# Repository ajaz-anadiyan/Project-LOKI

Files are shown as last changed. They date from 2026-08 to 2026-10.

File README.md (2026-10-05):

# 🚀 Project Loki: Bidirectional Free-Space Optical Communication

**Project Loki** is a two-way laser communication system built for the NIMS Dubai Expo. It demonstrates NASA's latest Free-Space Optical (FSO) satellite technology by transmitting data wirelessly through beams of light instead of radio waves. 

The project features **two identical transceiver stations**. Both stations can send and receive audio data at the exact same time over a single optical link.

---

## 🌟 Key Features
* **Two-Way Link:** Simultaneous transmission and reception (Full-Duplex).
* **Signal Conditioning:** Comparators turn weak photodiode light signals into sharp digital square waves.
* **Logic-Level Control:** Low-power ESP32 pins safely switch a 5V laser using high-speed MOSFETs.
* **Dual Demo Inputs:** Supports live voice from a microphone or digital MP3 file streaming.
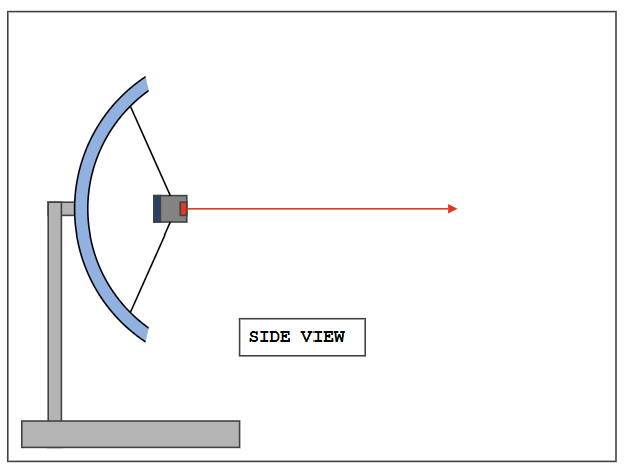
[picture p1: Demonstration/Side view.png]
Side view

---

## 🛠️ How It Works

### Signal Flow Matrix
![Project Loki Transceiver Diagram](https://kroki.io/plantuml/svg/eNqtVm1v2kgQ_u5fMSJSk0ixitemgRO1uhi7RWcDwk4bqeqHBRawYrxovVwvd8p_v_VL8BaTNNdmI0Vo5tmZ2efZGe-HTBAu9ttEOwdd18FJKEkh4iTNdoTTVMCUsxXNspilJIG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)

### Schematics (KiCAD)
<picture>
  <source media="(prefers-color-scheme: dark)" srcset="Demonstration/schematics_dark.svg">
  <source media="(prefers-color-scheme: light)" srcset="Demonstration/schematics_light.svg">
  Project LOKI Schematic
</picture>

### 3D model (Fusion360)
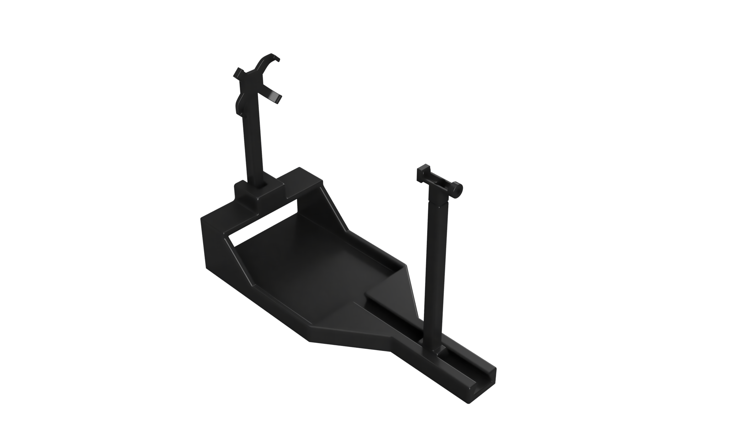
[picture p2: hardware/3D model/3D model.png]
3D model

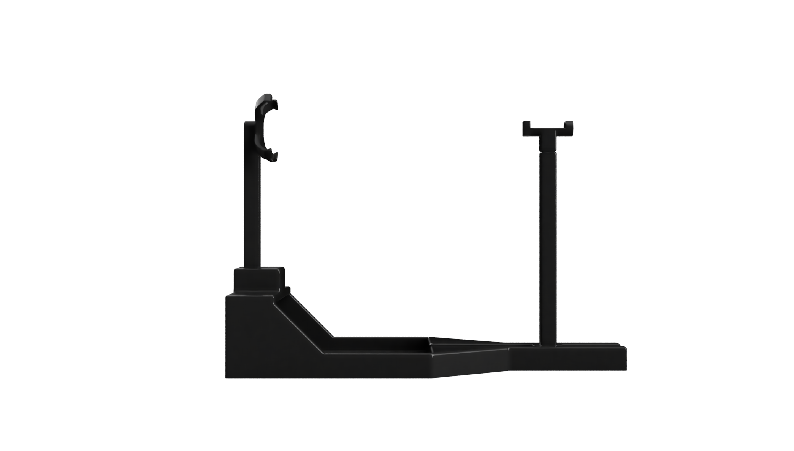
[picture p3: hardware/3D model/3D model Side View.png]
3D model Side View

---

## 🎧 Expo Demonstration Modes

Visitors can interact with the project using two different modes:

### 1. Live Voice Mode (Intercom Demo)
* Speaks into the microphone at Station 1.
* The ESP32 digitizes the voice and flashes it across the room via the laser.
* Station 2 receives the beam and plays the audio instantly through the speaker.

### 2. MP3 Music Mode (Data Streaming Demo)
* Plays a mp3 audio file from laptop/mobile to other station speaker.
* Demonstrates that optical links can handle high-bandwidth digital data streams.

### 🖼️ Expo Setup Layout
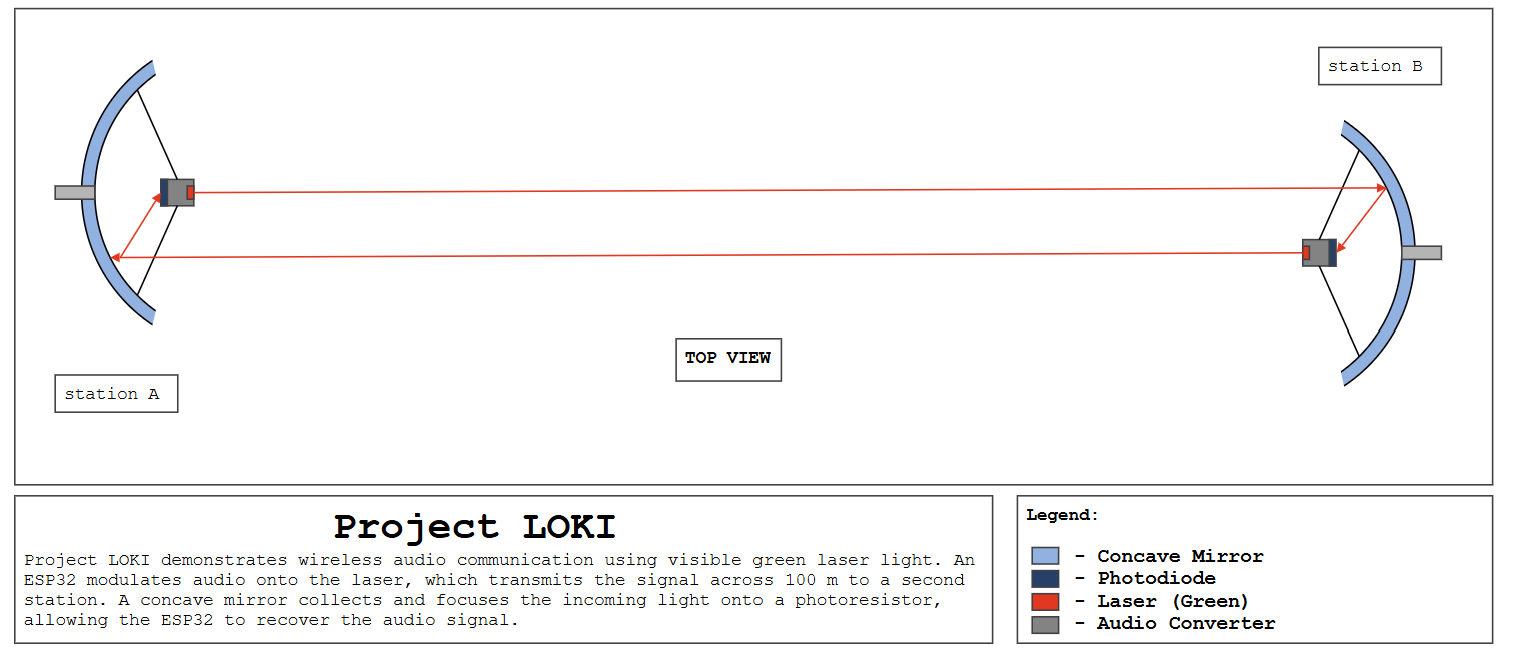
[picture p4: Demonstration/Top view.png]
Top view


---

## 📋 Component Checklist (Per Station)

Both stations use identical hardware:
* **Brain:** 1x ESP32 Microcontroller
* **Light Source:** 1x 5V Laser Diode
* **MOSFET:** 1x ZVN2106
* **Receiver:** 1x BPW34 PIN Photodiode
* **Signal Cleaner:** 1x Voltage Comparator (LM311)
* **Audio Input:** 1x Microphone Module (INMP441 I2S)
* **Audio Output:** 1x Audio Amplifier (MAX98357 I2S DAC) Module & 8Ω Speaker
* **Power Source:** 2x LiON 18650 (2S)
* **Extras:** 1x MP1584EN FIXED OUT 5V , capacitors, Resistors, Potentiometer (L 10k)

---

## 🔬 Core Scientific Principles

* **Photoconductive Mode:** The BPW34 uses reverse-bias power to react fast enough to catch digital audio frequencies.
* **Threshold Adjustment:** A comparator filters out background room lights by looking only for the intense laser brightness.
* **Low-Side Switching:** The MOSFET bridges the 3.3V microcontroller logic and the 5V laser power supply safely on the ground line.

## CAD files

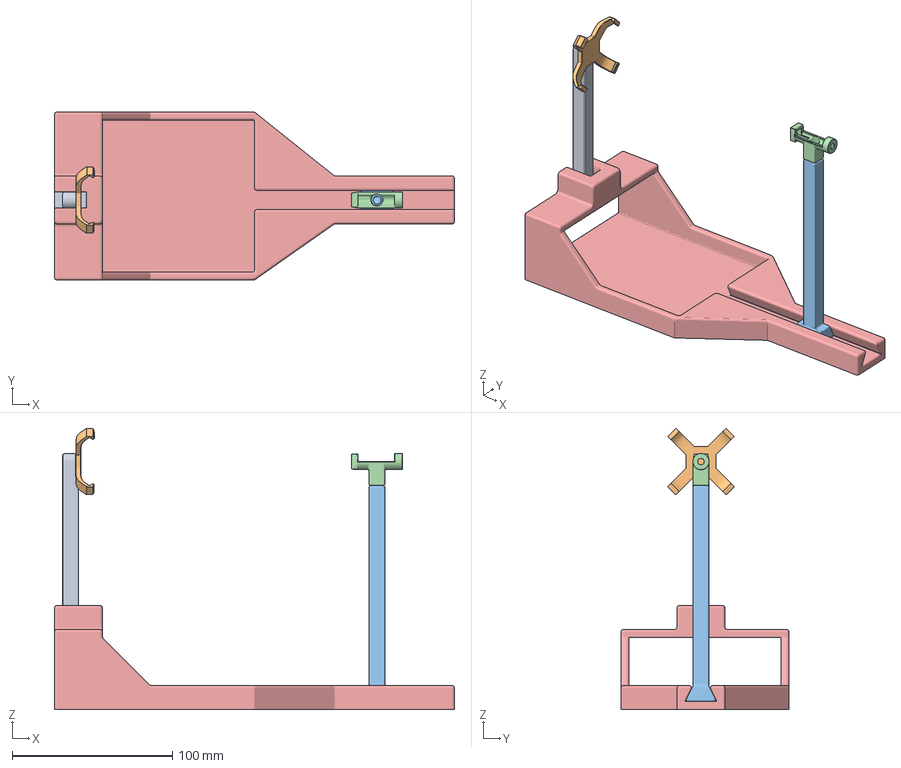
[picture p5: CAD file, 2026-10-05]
hardware/3D model/3D model.3mf
250.0 x 105.0 x 175.7 mm

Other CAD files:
hardware/3D model/3D model.f3z
hardware/3D model/3D model.stl

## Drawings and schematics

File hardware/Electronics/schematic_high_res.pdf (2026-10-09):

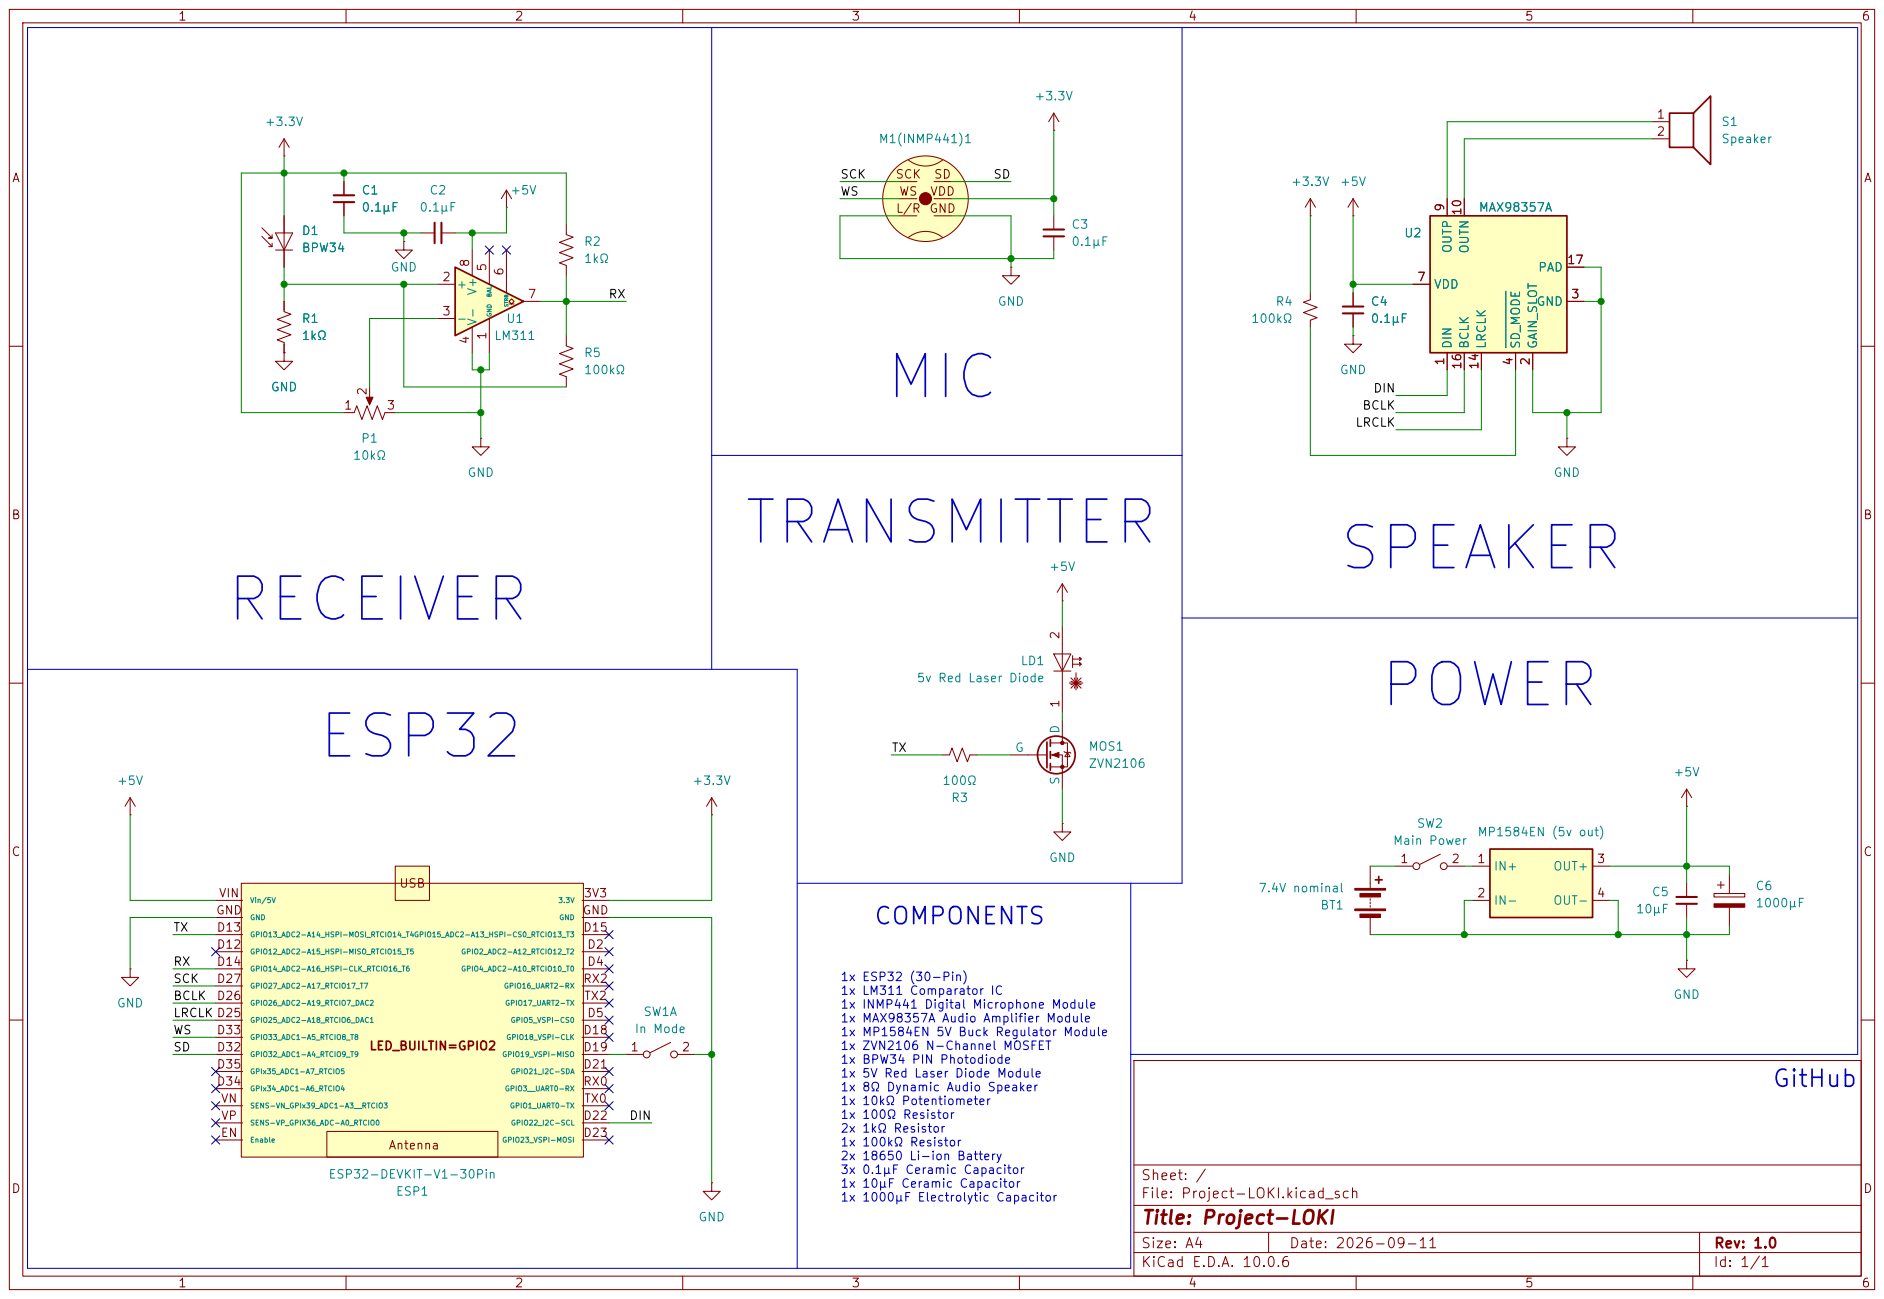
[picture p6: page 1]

9 OUTN 10 LRCLK 14 BCLK 16 PAD 17 U2 MAX98357A +5V +3.3V GND USB

9 OUTN 10 LRCLK 14 BCLK 16 PAD 17 C4

1x INMP441 Digital Microphone Module 1x MAX98357A Audio Amplifier Module 1x MP1584EN 5V Buck Regulator Module 1x ZVN2106 N-Channel MOSFET 1x BPW34 PIN Photodiode 1x 5V Red Laser Diode Module 1x 8Ω Dynamic Audio Speaker 1x 10kΩ Potentiometer 1x 100Ω Resistor 2x 1kΩ Resistor 1x 100kΩ Resistor 2x 18650 Li-ion Battery 3x 0.1µF Ceramic Capacitor 1x 10µF Ceramic Capacitor 1x 1000µF Electrolytic Capacitor

Size: A4 | Rev: 1.0
KiCad E.D.A. 10.0.6 | Id: 1/1

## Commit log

2026-08-30 Remove ASCII art from DSOC section of README
    Removed ASCII art representation of laser communication.
2026-08-30 Update README with project diagram and cleanup
    Replaced text diagram with an image for clarity and removed placeholder sections for circuit schematic and prototype models.
2026-09-10 Revise audio components and add power source details
    Updated audio input and output components with specific models and added power source and extras.
2026-09-11 Add Schematics section to README
    Added a new section for Schematics in KiCAD to the README.
2026-09-11 added kicad schematics
2026-09-11 Add responsive images for KiCAD schematics
    Added responsive images for KiCAD schematics based on color scheme preference.
2026-09-12 added high res pdf file of schematic
2026-09-16 Revise hardware components in README
    Updated component specifications for laser driver and signal cleaner.
2026-09-17 Update MOSFET to Transistor 2N2222 in README
2026-09-18 changed, mosfet, comparator, added switches
2026-09-18 Replace 2N2222 transistor with ZVN2106 MOSFET
2026-10-05 add 3d Model of loki stand
    [3D model.3mf, 3D model.f3z, 3D model.stl]
2026-10-09 added schematic
